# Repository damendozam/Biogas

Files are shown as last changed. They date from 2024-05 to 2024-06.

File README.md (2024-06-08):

# Materiales de construcción
## Sensores
| Tipo  | Referencia |Descripción|
| --- | --- |-----|
| CO2 | MQ135  | Se usa para medir la calidad del aire, por lo que mediria la suma de varios gases incluyendo el Metano|
| CH4 | MQ4  | Se usa para solo medir concentracion de Metano
| Temperatura, Humedad, Presión | TARJ BME280 | Se usa para medir temperatura y humedad para ajustar la medición de concentración de gases y de presión |

## Calibración
### Plataforma de adquisición de datos
MDF 40x40 https://www.homecenter.com.co/homecenter-co/product/306118/tablero-40x40-cm-mdf-25-mm-escolar/306118/
Corte laser: Corte Laser Willows
Tornillo para unir base y tapa: https://www.homecenter.com.co/homecenter-co/product/592728/tornillo-estufa-cilindrico-tuerca-m5-x-20-mm2u/592728/

### MQ-135
```
A=-0.3513615;
B=-0.0025928;
C=-0.0010671;
D=0.8343359;

yy=1;
z=20;
u=85;

x=(yy*10**(-(B*z+C*u+D)))**(1/A)

disp(x)
```
### MQ-4
```
A=-0.3532477;
B=-0.0014940;
C=-0.00136591;
D=1.17718719;

yy=0.95;
z=20;
u=65;

x=(yy*10**(-(B*z+C*u+D)))**(1/A)

disp(x)
```
## Tanque de Biodigestor
Conector tanque: https://www.homecenter.com.co/homecenter-co/product/567540/conector-tanque-de-1-pulg-rosca-hembra/567540/

## Cargador de biogas
Materiales utilizados para el invento:

Compresor de nevera: Lo puedes comprar muy barato en una chatarrería
Bidón 220l.: https://amzn.to/3fMCjML

Grifo:  https://amzn.to/3tdVCBo

Filtro con regulador:  https://amzn.to/3EhrJGI

Racores para el bidón:  https://amzn.to/3GiGE5d

Válvula y tubo Gas:  https://amzn.to/3fP7g2C

Presostato sin modificar y válvula de alivio de presión:  https://amzn.to/3UfuDkZ

Tubo neumático y racores:  https://amzn.to/3UCLWgd

# Banco de pruebas calibración sensores de gas
## Bomba de vacio
https://articulo.mercadolibre.com.co/MCO-2207965998-bomba-electrica-intex-azul-_JM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

## Concentración de gases

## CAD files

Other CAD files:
Estructura/AcopleHembra.ipt
Estructura/AdaptadorBancoDePruebas.iam
Estructura/AdaptadorMacho.ipt
Estructura/ArduinoMega.ipt
Estructura/BaseMDF.idw
Estructura/BaseMDF.ipt
Estructura/ConectorFuente.ipt
Estructura/ConectorGasCamara.ipt
Estructura/Contenedor.ipt
Estructura/ContenedorTest.ipt
Estructura/ConversosDCDC.ipt
Estructura/Ensamble.iam
Estructura/LlaveDesecho.ipt
Estructura/Manometro.idw
Estructura/MaparoSensores.ipt
Estructura/PlanoManufactura.idw
Estructura/SensorGas.ipt
Estructura/SensorHumedad.ipt
Estructura/SensorPresionHumedadTemp.ipt
Estructura/TapaContenedorTest.ipt
Estructura/TornilloBaseTapa.ipt
Estructura/TuercaBaseTapa.ipt

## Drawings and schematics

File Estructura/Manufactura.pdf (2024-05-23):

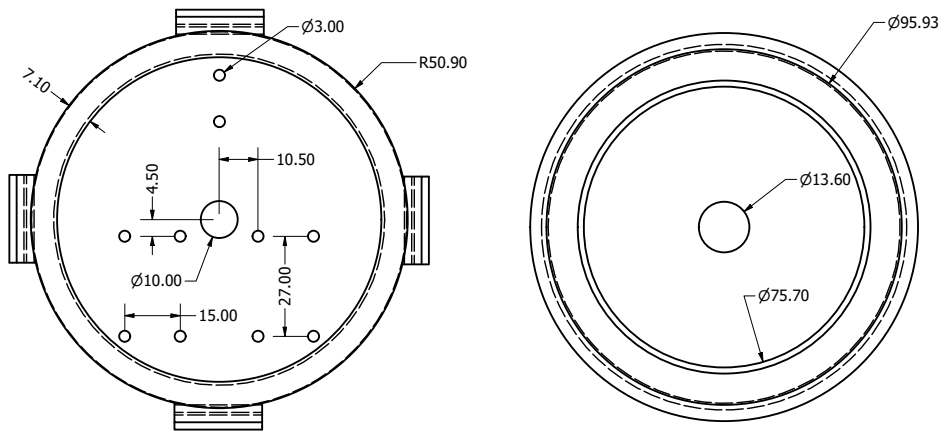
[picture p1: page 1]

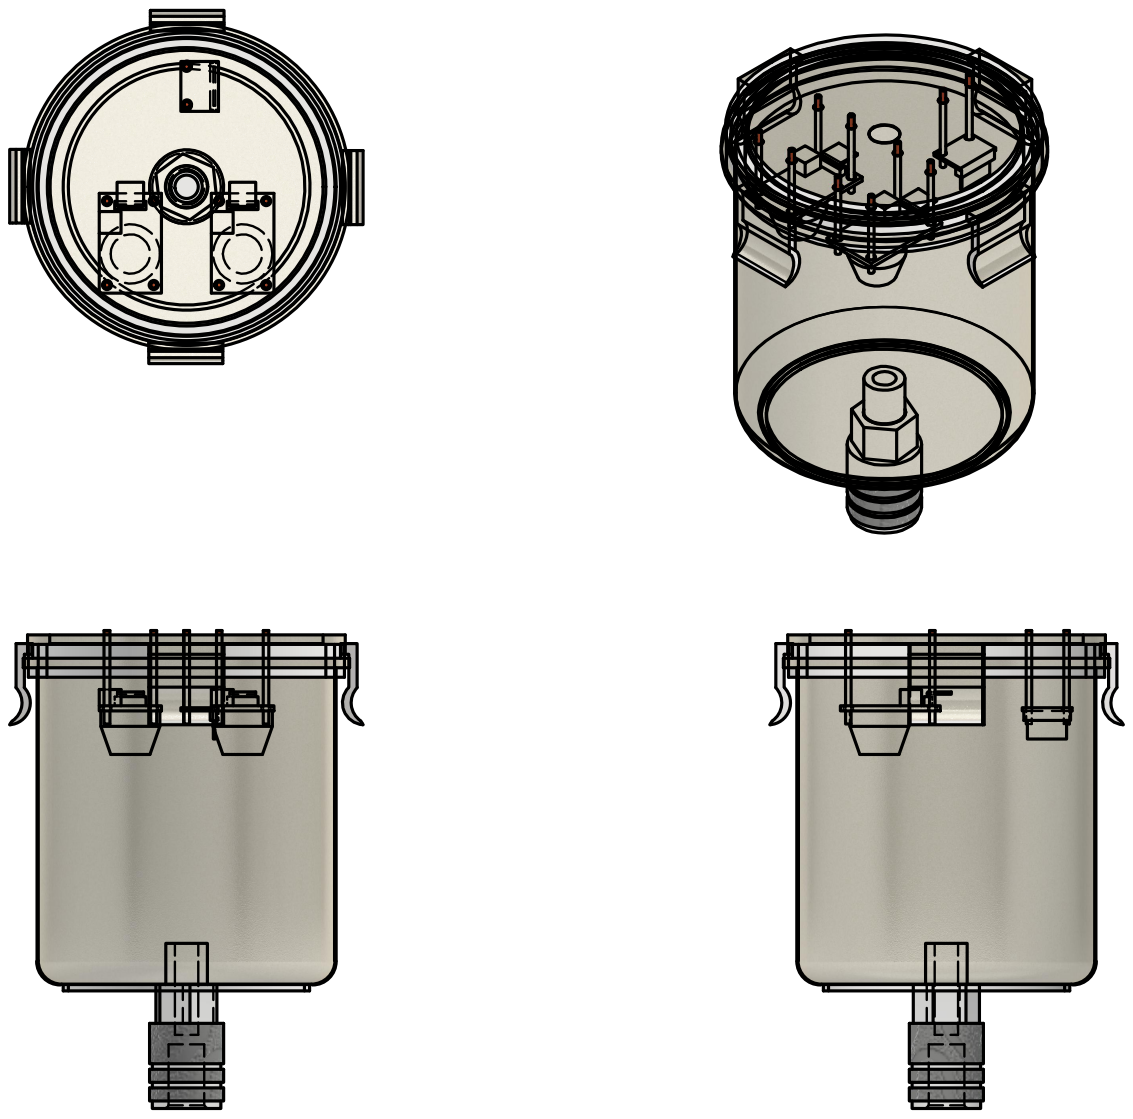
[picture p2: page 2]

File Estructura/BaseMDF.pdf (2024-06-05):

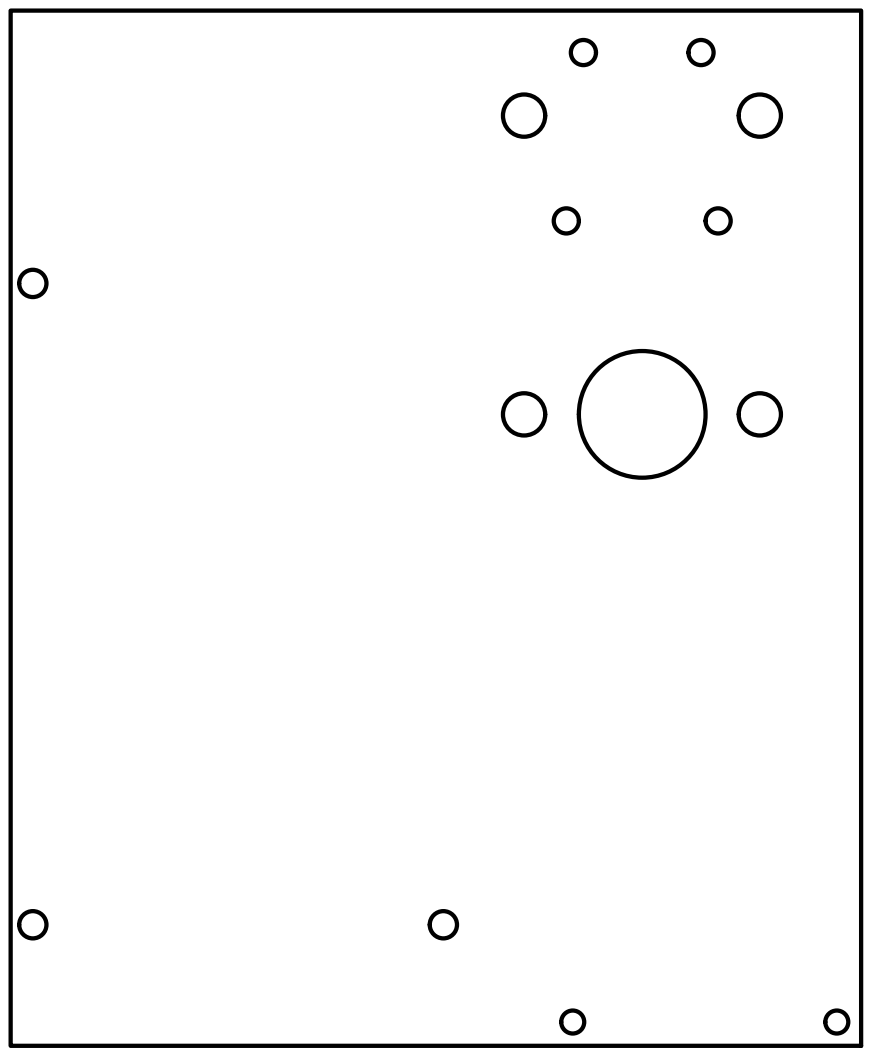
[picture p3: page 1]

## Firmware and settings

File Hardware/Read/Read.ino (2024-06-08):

#include <Wire.h>

#include "SparkFunBME280.h"
BME280 sensorHumTempPress; //Uses default I2C address 0x77

// MQ 135
double varAMQ135 = -0.3513615;
double varBMQ135 = -0.0025928;
double varCMQ135 = -0.0010671;
double varDMQ135 = 0.8343359;

// MQ 4
double varAMQ4 = -0.3532477;
double varBMQ4 = -0.0014940;
double varCMQ4 = -0.00136591;
double varDMQ4 = 1.17718719;

//RL
double varRL = 20; //valor en kOhm

double varR0MQ135=0;
double varR0MQ4=0;

void setup()
{
  Serial.begin(9600);
  Wire.begin();
  double varRLMQ135 = analogRead(A2);
  double varRLMQ4   = analogRead(A1); 
  double varVC      = analogRead(A0);

  double varRSMQ135 = (varVC*varRL/varRLMQ135) - varRL;
  double varRSMQ4   =  (varVC*varRL/varRLMQ4) - varRL;

  varR0MQ135 = varRSMQ135/3.6016140772527665;
  varR0MQ4   = varRSMQ4/4.4366873309786135;

  
  sensorHumTempPress.setI2CAddress(0x76); //Connect to a second sensor
  if(sensorHumTempPress.beginI2C() == false) Serial.println("Sensor connect failed");

  /*Serial.println(varRLMQ135);
  Serial.println(varRLMQ4);
  Serial.println(varVC);*/
}

void loop()
{

  double varZMQ135 = sensorHumTempPress.readTempC();
  double varZMQ4 = sensorHumTempPress.readTempC();

  double varUMQ135 = sensorHumTempPress.readFloatHumidity();
  double varUMQ4 = sensorHumTempPress.readFloatHumidity();

  double varRLMQ135 = analogRead(A2);
  double varRLMQ4   = analogRead(A1); 
  double varVC      = analogRead(A0);
  
  double varRSMQ135 = (varVC*varRL/varRLMQ135) - varRL;
  double varRSMQ4   =  (varVC*varRL/varRLMQ4) - varRL;

  double varYMQ135 = varRSMQ135/varR0MQ135;  //Sensibilidad [Ohm/Ohm]
  //double varZMQ135 = 20; //Temperatura [°C]
  //double varUMQ135 = 65; //Humedad [%]

  double varYMQ4 = varRSMQ4/varR0MQ4;  //Sensibilidad [Ohm/Ohm]
  //double varZMQ4 = 20; //Temperatura [°C]
  //double varUMQ4 = 65; //Humedad [%]

   

  double varXMQ135 = pow(varYMQ135 * pow(10,-(varBMQ135 * varZMQ135 + varCMQ135 * varUMQ135 + varDMQ135)),1/varAMQ135);  //Concentración MQ 135 [ppm]
  /*Serial.print("MQ 135: ");
  Serial.print(varXMQ135);
  Serial.print("\t,\t");*/

  double varXMQ4 = pow(varYMQ4 * pow(10,-(varBMQ4 * varZMQ4 + varCMQ4 * varUMQ4 + varDMQ4)),1/varAMQ4);  //Concentración MQ 4 [ppm]
  /*Serial.print("MQ 4: ");
  Serial.println(varXMQ4);*/

  Serial.print(varRLMQ135*5000/1023);
  Serial.print(",");
  Serial.print(varRLMQ4*5000/1023);
  Serial.print(",");
  Serial.print(varYMQ135);
  Serial.print(",");
  Serial.print(varYMQ4);
  Serial.print(",");
  Serial.print(varXMQ135);
  Serial.print(",");
  Serial.print(varXMQ4);
  Serial.print(",");
  Serial.print(varZMQ135);
  Serial.print(",");
  Serial.print(varUMQ135);
  Serial.println();

}

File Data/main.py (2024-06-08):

import serial
f = open('data.csv','a')
arduino = serial.Serial('COM4', 9600)

f.write('VoltajeMQ135,VoltajeMQ4,SensibilidadMQ135,SensibilidadMQ4,ConcentracionMQ135,ConcentracionMQ4,Temperatura,Humedad\n')
while True:
    rawString = arduino.readline().decode("utf-8").replace('\r\n', '')
    f.write(rawString+'\n')
    print(rawString)

f.close()
arduino.close()

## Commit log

2024-05-19 Adicion de sensores
    [AcopleHembra.ipt, AdaptadorBancoDePruebas.iam, ContenedorTest.ipt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]
2024-05-19 documentación para bomba de vacio
    [Manometro.idw]
2024-06-02 Actualizacion hardware
    [PlanoManufactura.idw]
2024-06-05 Restructuraci{on de proyecto y adicion de base para electronica
    [AcopleHembra.ipt, AdaptadorBancoDePruebas.iam, AdaptadorMacho.ipt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]
2024-06-08 Lectura y alamcenamiento en archivo
    [Ensamble.iam, data.csv]
